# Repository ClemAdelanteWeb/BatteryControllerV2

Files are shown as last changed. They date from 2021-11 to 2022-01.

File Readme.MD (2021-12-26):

### 2021-12-26 
Refonte complète du PCB pour y intégrer une horloge et un support de carte SD pour faire du logging.

Ajout d'une sortie Charging qui permet de couper / lancer une source de charge en fonction de l'état de la batterie.

Une temporisation de quelques secondes a été insérée pour que cette sortie Charging = 0 avant que le relais de Charge ne soit réellement ouvert (charge bloquée), pour éviter quel l'alternateur ne débite d'un coup dans la batterie moteur ou que l'alternateur d'arbre continue de débiter à fond dans la batterie moteur.

Une sortie RS485 est intégrée pour afficher les informations depuis un autre Arduino. L'arduino NANO manque cruellement de RAM et SRAM pour permettre d'autre développement, comme le logging des valeurs les plus hautes ou plus basses (tensions de la batterie ou des cellules), etc.

Ces développements se feront peut-être avec un Arduino Nano Every ou STM32 Nucleo par exemple. Mais je réfléchis à une V3 avec un ESP32, ce qui permettrait d'émettre les informations en WIFI ou bluetooth BLE.

VIA RS485, les commandes sont les suivantes :
- 0 : print status
- 1 : print all data stored in SD CARD
- 9 : remove SD card file
- 8 : create SD Card file and add first entry in it

### dernier update 2020-01-08
Modification du comportement de la détection du voltage minimum de la batterie suite à un problème pendant 2 mois d'absence.
Le SOC était toujours à 100% parce que le Victron ne détectait pas les petites consommations de courant (Victron BMV lui-même, contrôleur de batterie, conso du régulateur de panneau solaire). Le relai de charge ne s'est dont pas fermé et à mon retour la batterie était à 10.7v

J'ai aussi rajouté des détections de voltage trop haut ou trop bas pour chaque cellule. Respectueusement 2.8v et 3.8v.

### Gestion des relais de charge et décharge dans un système de batterie Lifepo4.

Dans un système avec batteries au lifepo4, il faut pouvoir couper la charge quand les batteries sont pleines, pour ne pas passer en mode float et abimer les batteries sur le long terme.

Toute décharge doit être rendue impossible si les batteries ont atteint leur maximum de capacité de décharge (en général 80%), tout en laissant la charge se faire.
Il faut donc deux relais qui permettent de bloquer la charge, bloquer la décharge et bloquer les deux ce qui ferait l'équivalent d'un coupe circuit.

Il existe plusieurs sortent de relais. Les classiques à solenoide qui sont finalement constitués d'une lamelle à ressort que vient plaquer et fermer une bobine qui une fois alimentée crée un champ magnétique. Cette bobine c'est une solénoide, qu'on retrouve dans tous les relais classiques.

Il est aisé de déduire que ce type de relai consomme de l'énergie en permanence pour que le contact se fasse et le courant puisse passer. Pour les meilleurs d'entre eux 0.1A 24/24h ce qui fait un total de 2.4Ah par jour et comme il en faut 2 on arrive à une consommation de 4.8Ah par jour.

Un relai classique consomme entre 0.3 et 1A, on arrive dans ce cas à des consommations non négligeables de 14Ah à 48Ah par jour, simplement pour alimenter des relais qui servent à :
- Celui de charge (Charge) : couper les différentes charges et ne pas laisser la batterie Lifepo4 en mode float
- Celui de décharge (Load) : isoler de toute décharge profonde la batterie Lifepo4 tout en laissant la possibilité de la charger.

Les relais à solénoide optimisés (0.1A) sont très chers et même 5Ah par jour étaient de trop pour moi. 

Il existe aussi des relais mosfet qu'on trouve partout en électronique de puissance. S'il est plus compliquer d'estimer leur consommation lorsqu'ils sont passant, on comprend vite qu'elle est élevée puisqu'il faut un radiateur pour dissiper la chaleur qu'il produit.
Les mosfets sont aussi évincés de ma liste.

Heureusement il reste une solution : les relais bi-stable (ou latching relay en anglais).
Ceux-ci possèdent deux solénoides par relai. Un pour ouvrir le contact et un autre pour le fermer. Cette fois ci, et au contraire des relais classique, la position de la lamelle est permanente. C'est à dire qu'il n'y a pas besoin d'alimenter en permanence le solénoide pour créer un champ magnétique et forcer à lamelle à rester en place. Ici, comme pour un interrupteur à deux positions le relai ne consomme du courant que pour changer son état.

C'est parfait sauf que ça complique les choses puisqu'il y a deux bobines à alimenter par relai. Et comment savoir dans quelle position est le relai, ouvert ou fermé ?

J'ai choisi d'utiliser les relais Blue Sea ML-RBS qui ne consomment aucun courant et ont aussi une sortie qui permet de connaitre l'état du relai (ouvert ou fermé). On peut récupérer cette information et la traiter avec l'Arduino.

Il faut au moins 2A en 12v pour ouvrir ou fermer le relai. L'arduino seul n'est pas capable de fournir une tel intensité ni un telle tension. J'utilise donc une cascade de transisteurs.

Le soucis majeur lors de la création de la carte a été que les relais sont cablés en High Side, c'est à dire que les solenoides se trouvent du côté positif du circuit ce qui implique d'utiliser une cascade de transistor pour les activer avec un système PNP + NPN.

Pour déterminer le SOC (capacité restante dans la batterie en pourcentage) et l'utiliser pour gérer mes relais, j'utilise mon controleur de batterie Victron BMV702 qui fournit cette information par son port de communication (VE Direct). 

J'ai ensuite pris le parti d'acquérir les tensions des 4 cellules que composent la batteries pour controller les écarts entre les cellules, vérifier si l'une d'entre elles venait à être sous-chargée ou sur-chargée et connaitre la tension totale de la batterie.

Autant d'informations capitales qui permettent aussi de controller les relais sans les données fournies par le Victron, si celui-ci venait à tomber en panne.

J'ai aussi ajouté un bouton ON/OFF pour désactiver l'utilisation du SOC venant du Victron.

L'arduino reçoit donc les informations suivantes : 
- Etat du relai de charge
- Etat du relai de décharge
- SOC via le controleur Victron
- Tension de chaque cellule
- Utilisation du Victron ON / OFF

Par la suite, je vais créer un petit écran pour afficher toutes les données (voltage des cellules, état des relais, cycle de charge ou cycle de décharge, sur-tension ou sous-tension détectée). 

Pour des batteries au lithium, il n'est pas recommandé de maintenir la charge à 100% (mode float).
Aujourd'hui le programme ne possède qu'un cycle de charge qui va de 95 à 100% du SOC. Un cycle se compose comme ceci : la batterie se charge jusqu'à 100%, puis la charge est bloquée jusqu'à ce que la batterie se vide de 5%. A 95% de SOC, donc, la charge est de nouveau autorisée. 

Pour prolonger la durée de vie des batteries lithium, le SOC idéal est entre 50 et 70%. Ce serait intéressant de pouvoir faire des cycles entre 50 et 70% lorsque l'on est au port par exemple et qu'on n'a pas besoin de toute la capacité de la batterie puisqu'elle est rechargée au quai. 
Une autre utilisation de ce cycle 50-70% pourrait être faite en hivernage, période pendant laquelle la batterie n'est pas solicitée mais que la charge peut être faite par un panneau solaire par exemple. Grâce au controleur il serait possible de laisser tourner un petit ventilateur 12V dans les endroits qui en auraient besoin, par exemple, en aillant la certitude qu'il ne déchargera pas la batterie en dessous de 50%.

Une fois que l'autonomie totale est requise on retourne sur le cycle normal qui est de 95 à 100%.

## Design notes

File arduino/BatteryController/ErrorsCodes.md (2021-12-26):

#1 SOC min reached : now / min 
    values : SOC actual/ SOC Min param
#2 High Voltage detected
    values : Voltage
#3 High voltage detected, Force Opening Charge Relay 
#4  Voltage Max Reset reached, charge relay closing
#5 Low voltage detected
#6 Charge Relay Closing
    value : SOC, Battery voltage
#7 Low voltage detected, Load relay force closing
#8 Charge relay force closing. 2nd attempt
#9 Voltage min Reset reached. Load Relay closing
#10 No Voltage detected Load Relay Force Open
    value : temps écoulé depuis dernière valeur en ms
#11 Cells Voltage diff high, Load relay Force open
    value : mV cell diff 
#12 Reset OK Cells Voltage diff < Rst. Closing Load Relay
#13 Cells diff upd > 10s
#14 ADS 3 cell voltage not available
#15 SOC Current > SOC Min
    => normal routine detection
#16 Load relay closing, routine without SOC
#17 SOC Current < SOC Max Charge relay closing
    => can happen when forcing open Charge Relay manually 
#18 Charge relay closing, routine without SOC
#19 SOC min reset reached
    values : SOCCurrent/SOCMinReset
#20 Loading relay closing, routine without SOC    
#21 Cancelling Discharge Cycling
    values : SOCCurrent/SOCMaxReset
#22 Cancelling Discharge Cycling without SOC
#23 Wrong Charging relay state, opening 
    => Can append when manually closing Charge Relay
    => Can also append when HighVoltage detected is going to be RESET AND SOC is just reconnected, normal routine
#24 Wrong Loading relay state, opening
#25 SOC Current > Max : current/max
#26 High individual cell voltage
    value : num / mV
#27 RST OK : high V cell good
    value : Highest cell voltage in mV
#28 Low cell voltage
    value : num / mV
#29 RST Cell Voltage
    value : Lowest cell voltage in mV
#30 Low T°
    value : T°
#31 Low T°
    value : T°
#32 T° min reset, closing charging relay

               MessageTemp = (String)SOCCurrent + F(",") + TxtSpacer + (String)SOCMin;
               logDataMessNum(15);

sprintf(messageStatusBuffer, ("$%d;%d;%d;;%d;%d;%d;%d;%d;;%d;%d;;%d;%d;%d;%d;;%d;%d;%d;%d;%d;%d*"),
          getBatteryVoltage(),
          getBatteryTemperature(),
          getBatterySOC(),
          // vide
          getAdsCellVoltage(0),
          getAdsCellVoltage(1),
          getAdsCellVoltage(2),
          getAdsCellVoltage(3),
          getMaxCellVoltageDifference(),
          // vide
          ChargeRelay.getState(),
          LoadRelay.getState(),
          // vide
          SOCChargeCycling,
          SOCDischargeCycling,
          isEnabledBMVSerialInfos(),
          isUseBMVSerialInfos(),
          // vide
          LowVoltageDetected,
           ,
          CellsDifferenceDetected,
          CellVoltageMinDetected,
          CellVoltageMaxDetected,
          LowBatteryTemperatureDetected

  );

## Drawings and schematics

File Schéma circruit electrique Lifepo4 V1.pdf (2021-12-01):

@

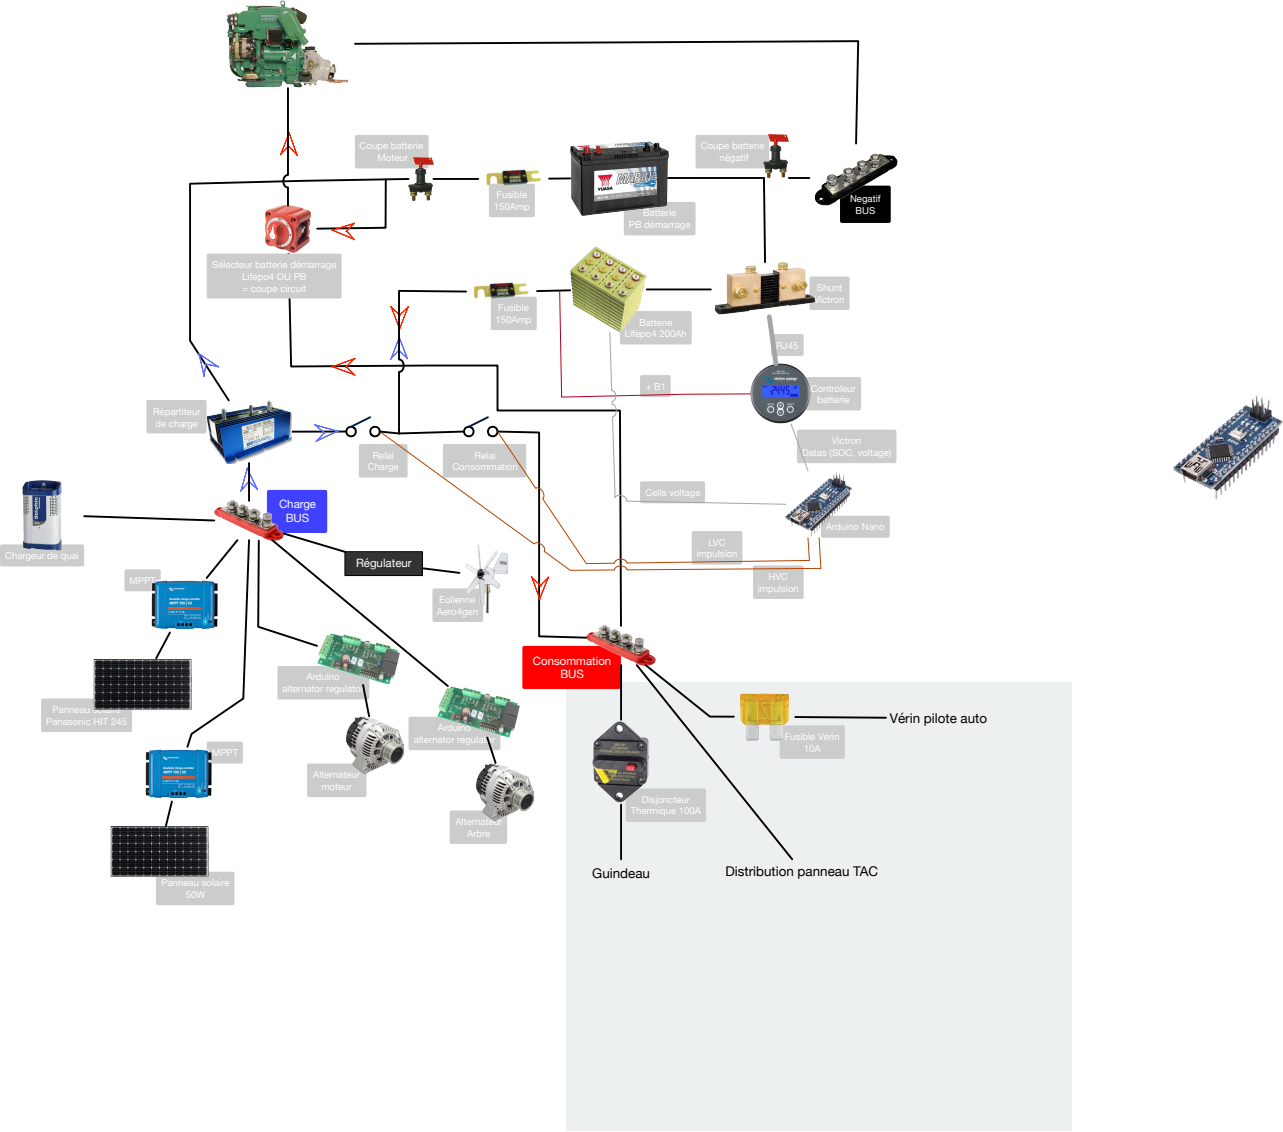
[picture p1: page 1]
Fusible Vérin 10A; Disjoncteur Thermique 100A; Coupe batterie négatif; Cells voltage; LVC impulsion; HVC impulsion; Arduino Nano; Controleur; batterie; Fusible 150Amp; Shunt Victron; Negatif BUS; Eolienne Aero4gen; Batterie PB démarrage; Batterie Lifepo4 200Ah; Arduino alternator regulator; Alternateur moteur; Alternateur Arbre; MPPT; Panneau solaire Panasonic HIT 245; Charge BUS; Consommation BUS; Répartiteur de charge; Relai Charge; Relai Consommation; Guindeau; Distribution panneau TAC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

Sélecteur batterie démarrage
Lifepo4 OU PB
= coupe circuit

Victron
Datas (SOC, voltage)

Chargeur de quai

Vérin pilote auto

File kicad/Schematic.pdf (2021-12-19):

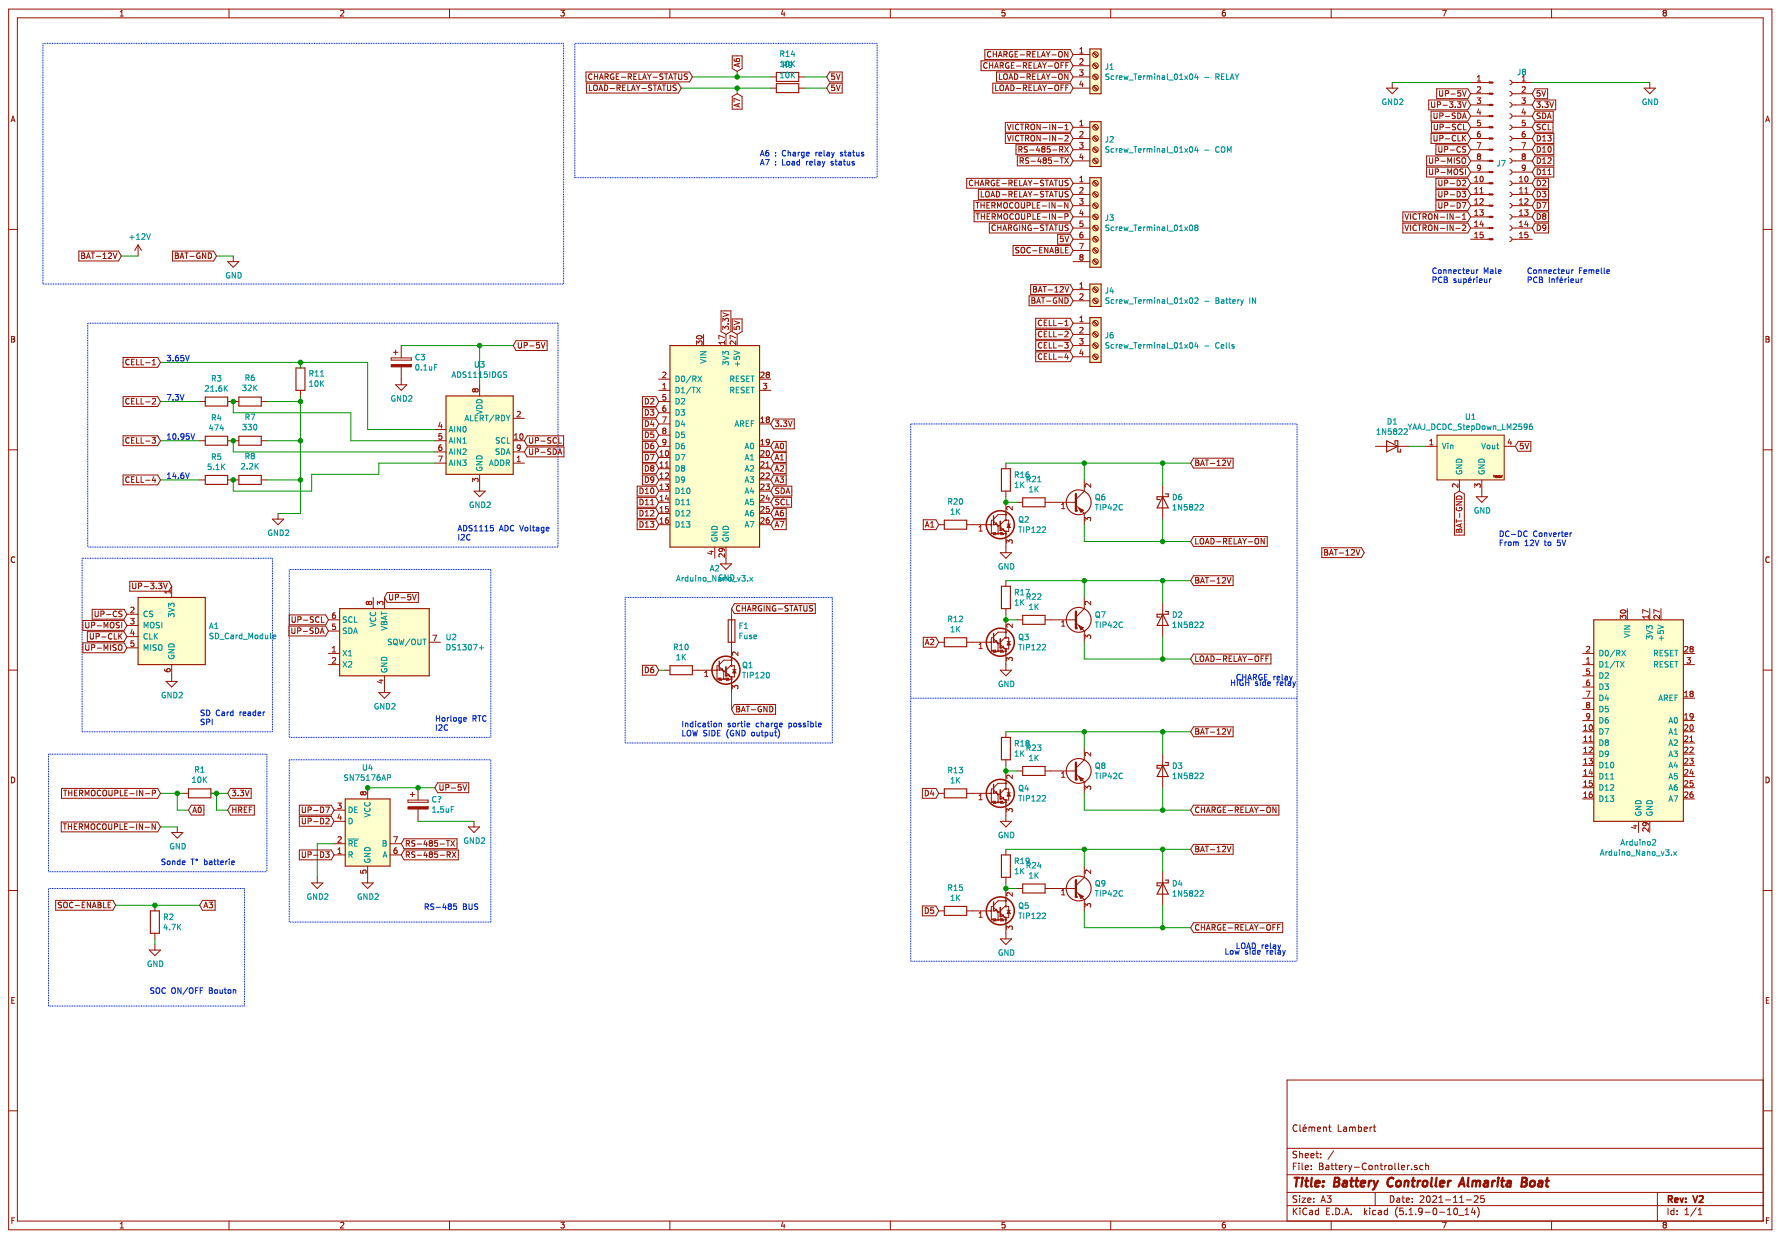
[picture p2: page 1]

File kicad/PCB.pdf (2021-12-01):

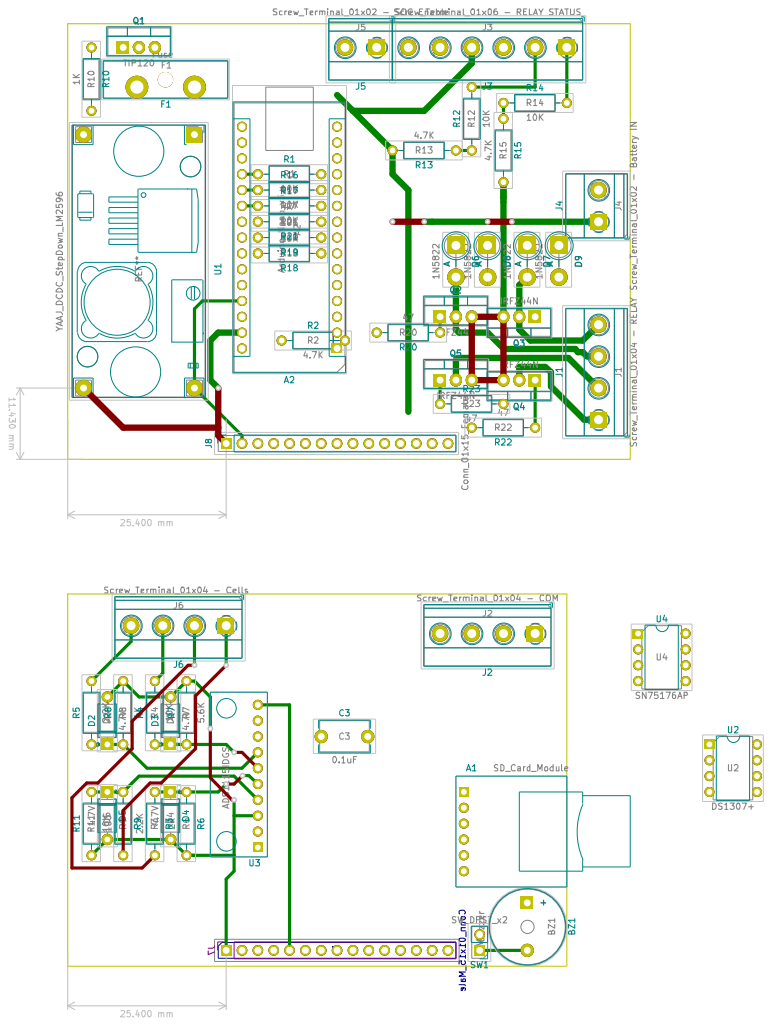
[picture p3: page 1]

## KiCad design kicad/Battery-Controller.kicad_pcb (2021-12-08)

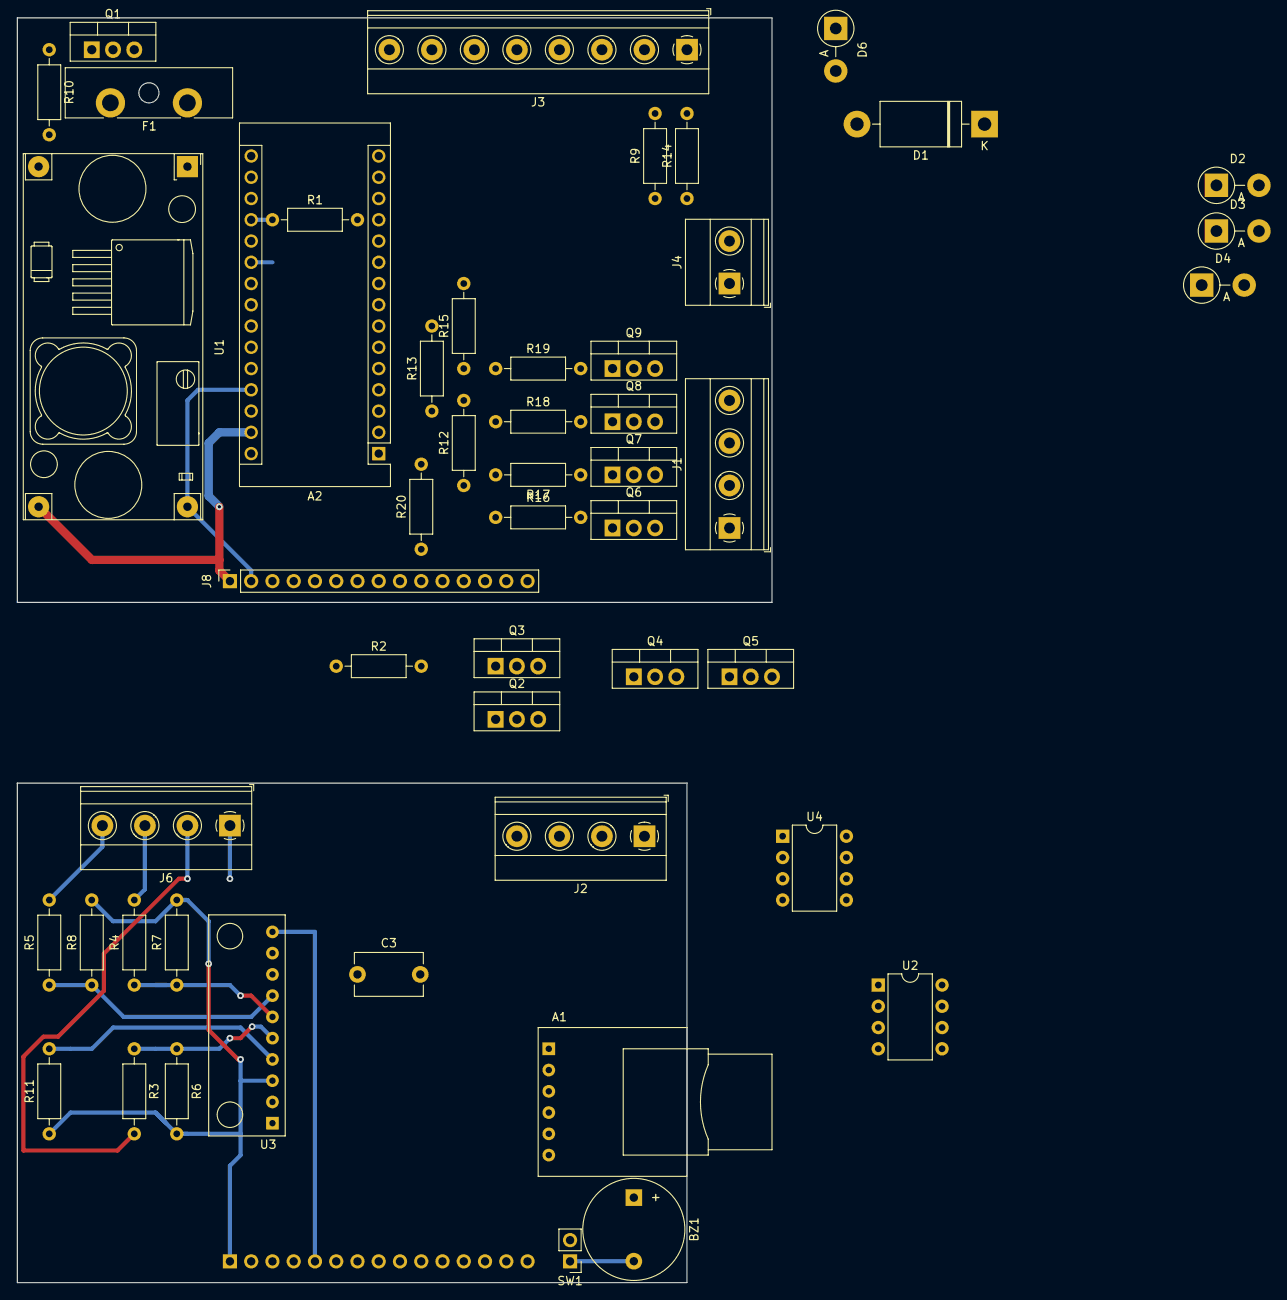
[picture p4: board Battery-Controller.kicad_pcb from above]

Board: 2 copper layers, 90.2 x 151.1 mm, 51 parts (1 on the bottom side), 64 nets.

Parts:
A1: SD_Card_Module
A2: Arduino_Nano_v3.x; Arduino_Nano
BZ1: Buzzer; Buzzer_12x9.5RM7.6
C3: 0.1uF; C_Disc_D8.0mm_W5.0mm_P7.50mm
D1: 1N5822; D_DO-201AD_P15.24mm_Horizontal
D2, D3, D4, D6: 1N5822; D_5W_P5.08mm_Vertical_AnodeUp
F1: Fuse; Fuseholder_Blade_ATO_Littelfuse_Pudenz_2_Pin
J1: Screw_Terminal_01x04 - RELAY; TerminalBlock_Phoenix_MKDS-1,5-4-5.08_1x04_P5.08mm_Horizont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
J2: Screw_Terminal_01x04 - COM; TerminalBlock_Phoenix_MKDS-1,5-4-5.08_1x04_P5.08mm_Horizont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
J3: Screw_Terminal_01x08; TerminalBlock_Phoenix_MKDS-1,5-8-5.08_1x08_P5.08mm_Horizont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
J4: Screw_Terminal_01x02 - Battery IN; TerminalBlock_Phoenix_MKDS-1,5-2-5.08_1x02_P5.08mm_Horizont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
J6: Screw_Terminal_01x04 - Cells; TerminalBlock_Phoenix_MKDS-1,5-4-5.08_1x04_P5.08mm_Horizont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
J7: Conn_01x15_Male; PinHeader_1x15_P2.54mm_Vertical
J8: Conn_01x15_Female; PinSocket_1x15_P2.54mm_Vertical
Q1: TIP120; TO-220-3_Vertical
Q2, Q3, Q4, Q5: TIP122; TO-220-3_Vertical
Q6, Q7, Q8, Q9: TIP42C; TO-220-3_Vertical
R1, R9, R11, R14: 10K; R_Axial_DIN0207_L6.3mm_D2.5mm_P10.16mm_Horizontal
R2: 4.7K; R_Axial_DIN0207_L6.3mm_D2.5mm_P10.16mm_Horizontal
R3: 21.6K; R_Axial_DIN0207_L6.3mm_D2.5mm_P10.16mm_Horizontal
R4: 474; R_Axial_DIN0207_L6.3mm_D2.5mm_P10.16mm_Horizontal
R5: 5.1K; R_Axial_DIN0207_L6.3mm_D2.5mm_P10.16mm_Horizontal
R6: 32K; R_Axial_DIN0207_L6.3mm_D2.5mm_P10.16mm_Horizontal
R7: 330; R_Axial_DIN0207_L6.3mm_D2.5mm_P10.16mm_Horizontal
R8: 2.2K; R_Axial_DIN0207_L6.3mm_D2.5mm_P10.16mm_Horizontal
R10, R12, R13, R15, R16, R17, R18, R19, R20: 1K; R_Axial_DIN0207_L6.3mm_D2.5mm_P10.16mm_Horizontal
SW1: SW_DPST_x2; PinHeader_1x02_P2.54mm_Vertical
U1: YAAJ_DCDC_StepDown_LM2596
U2: DS1307+; DIP-8_W7.62mm
U3: ADS1115IDGS; ADC1115_ADC_Module
U4: SN75176AP; DIP-8_W7.62mm

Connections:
3.3V: A2.17, J8.3, R1.2
5V: A2.27, J3.6, J8.2, R9.1, R14.1, U1.4
A0: A2.19, J3.4, R1.1
A1: A2.20, R20.2
A2: A2.21, R12.2
A3: A2.22, J3.7, R2.1
A6: A2.25, J3.1, R14.2
A7: A2.26, J3.2, R9.2
BAT-12V: D2.2, D3.2, D4.2, D6.2, F1.1, J4.1, Q6.2, Q7.2, Q8.2, Q9.2, R16.1, R17.1, R18.1, R19.1
BAT-GND: A2.29, J3.3, J4.2, J8.1, Q2.3, Q3.3, Q4.3, Q5.3, R2.2, U1.2, U1.3
CELL-1: J6.1, R11.2, U3.4
CELL-2: J6.2, R3.2
CELL-3: J6.3, R4.2
CELL-4: J6.4, R5.2
CHARGE-RELAY-OFF: D2.1, J1.2, Q7.3
CHARGE-RELAY-ON: D6.1, J1.1, Q6.3
CHARGING-STATUS: J3.5, Q1.3
D2: A2.5, J8.10
D3: A2.6, J8.11
D4: A2.7, R13.2
D5: A2.8, R15.2
D6: A2.9, R10.2
D7: A2.10, J8.12
D8: A2.11, J8.13
D9: A2.12, J8.14
D10: A2.13, J8.7
D11: A2.14, J8.9
D12: A2.15, J8.8
D13: A2.16, J8.6
LOAD-RELAY-OFF: D4.1, J1.4, Q9.3
LOAD-RELAY-ON: D3.1, J1.3, Q8.3
unnamed: BZ1.2, SW1.1
unnamed: D1.1, U1.1
unnamed: F1.2, Q1.2
unnamed: Q1.1, R10.1
unnamed: Q2.1, R20.1
unnamed: Q2.2, Q6.1, R16.2
unnamed: Q3.1, R12.1
unnamed: Q3.2, Q7.1, R17.2
unnamed: Q4.1, R13.1
unnamed: Q4.2, Q8.1, R18.2
unnamed: Q5.1, R15.1
unnamed: Q5.2, Q9.1, R19.2
unnamed: R3.1, R6.1, U3.5
unnamed: R4.1, R7.1, U3.6
unnamed: R5.1, R8.1, U3.7
RS-485-OUT1: J2.3, U4.7
RS-485-OUT2: J2.4, U4.6
SCL: A2.24, J8.5
SDA: A2.23, J8.4
TUP-01: A1.6, BZ1.1, C3.2, J7.1, R6.2, R7.2, R8.2, R11.1, U2.4, U3.3, U4.5
UP-3.3V: A1.1, J7.3
UP-5V: C3.1, J7.2, U2.3, U3.8, U4.8
UP-CLK: A1.4, J7.6
UP-CS: A1.2, J7.7
UP-D2: J7.10, U4.4
UP-D3: J7.11, U4.1
UP-D7: J7.12, SW1.2
UP-MISO: A1.5, J7.8
UP-MOSI: A1.3, J7.9
UP-SCL: J7.5, U2.6, U3.10
UP-SDA: J7.4, U2.5, U3.9
VICTRON-IN-1: J2.1, J7.13
VICTRON-IN-2: J2.2, J7.14

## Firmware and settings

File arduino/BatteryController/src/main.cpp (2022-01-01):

#include <Arduino.h>
#include <SPI.h>
#include "AltSoftSerial.h"

#include "SoftwareSerial.h"
#include "Thread.h"
#include "BlueSeaLatchingRelay.h"
#include "ADS1X15.h"

// Utilisation du module RTC qui permet de logger avec l'heure réelle
#define IS_RTC 1

#define IS_SDCARD 1

// Utilisation de serial
#define IS_SERIAL 0

#define IS_RS485 1

// Définit la date dans le module RTC
#define SET_DATE 0

// print memory free
#define IS_PRINT_MEMORY 1

//------
// SETTINGS

// Opening charge relay for SOC >= SOCMax
const int SOCMax = 1000;

// Re-Close Charge Relay when SOCMaxReset is reached
const int SOCMaxReset = 950;

// Opening Load relay if SOC <= SOCmin
const int SOCMin = 180;

// Re-Close Load Relay when SOCMinReset is reached
const int SOCMinReset = 200;

// SOC Maximum time considerated valid
// must be > 10 000ms
// in mS
const int SOCMaxTimeValid = 30000;

// Maximum Voltage security
// default 13800
const int BatteryVoltageMax = 13800; // 13,8v = 3,45v / Cell

// Waiting for Max Reset Voltage after reaching Max Voltage (time to discharge the battery enough to use it)
// default 13360
const int BatteryVoltageMaxReset = 13200;

// Minimum Voltage security
// default 12000
const int BatteryVoltageMin = 12000; // 12V = 3v / Cell

// Waiting for Min Reset Voltage after reaching Min Voltage (time to re-charge the battery enough to use it)
// default 12800
const int BatteryVoltageMinReset = 12800; // 12,9  = 3,225v / Cell

// Minimum operating cell voltage
// default 2800
const int CellVoltageMin = 2800;

// Minimum cell voltage after a min detected
const int CellVoltageMinReset = 2900;

// Maximum operating cell voltage
// default 3600
const int CellVoltageMax = 3600;

// Maximum cell voltage after max dected
const int CellVoltageMaxReset = 3350;

// Delay time before opening the Charge Relay
// The charge Output status will be HIGH right away and the charge relay will be opened after the delay
// default 5 sec (5000)
const unsigned int delayBeforeChargeOpening = 5000;

//------
// PINS PARAMS
const byte LoadRelayClosePin = A1; // A1
const byte LoadRelayOpenPin = A2;  //A2
const byte LoadRelayStatePin = A7; //A7

const byte ChargeRelayClosePin = 4;  //4
const byte ChargeRelayOpenPin = 5;   //5
const byte ChargeRelayStatePin = A6; //A6

// if pin HIGH, BMV infos are collected
const byte ActivateBmvSerialPin = A3;

const byte ThermistorSensorPin = A0;

const byte RS485PinRx = 3;
const byte RS485PinTx = 2;
const byte RS485PinDE = 7;

const byte ChargingStatusOutputPin = 6;

// END PINS PARAMS
//------

// Number of cells in the battery
const byte cellsNumber = 4;

// ADS1115 Calibration at 10v *1000
// Ex: 10 / 18107 = 0,000552273
// cell 1, 2, 3, 4 etc
const float adc_calibration[cellsNumber] = {
    0.11947112,
    0.22990510,
    0.32871799,
    0.422045};

// number of sample taken to average cell voltage
// mode=4 so 128 samples per seconde = 8ms/sample
// delay of 2ms between samples so
#define ADS_SAMPLE_NBR 10

// LOGGING Params
#if IS_RTC
#include <TimeLib.h>
#include <DS1307RTC.h>
// RTC date time module
tmElements_t tm;
#endif

#if SET_DATE
const char *monthName[12] = {
    "Jan", "Feb", "Mar", "Apr", "May", "Jun",
    "Jul", "Aug", "Sep", "Oct", "Nov", "Dec"};
#endif

#if IS_PRINT_MEMORY
#include <MemoryFree.h>
#endif
// Log on SD Card

#if IS_SDCARD
#include <SdFat.h>
SdFat sd;
SdFile logFile;

uint8_t SDCardPinSelect = 10;
#define DataLogFile "log.txt"
#endif

//------
// Temperature sensor settings

const int ThermistorNominal = 11700;          // // resistance at 25 degrees C
const byte ThermistorTemperatureNominal = 20; // temp. for nominal resistance (almost always 25 C)
const byte ThermistorNbrSamples = 5;          // how many samples to take and average, more takes longer
const int ThermistorBetaCoefficient = 4370;   // The beta coefficient of the thermistor (usually 3000-4000)
const int ThermistorSerieResistor = 10000;    // the value of the 'other' resistor

// Température minimum pour autorisation de charge
// => ne pas charger une batterie au lithium en dessous de 0°
// la sonde n'étant pas parfaitement calibrée, 1° réel = 4° sur la sonde
const byte TemperatureMinCharge = 4;
const byte TemperatureMinChargeReset = 5; // valeur à partir de laquelle on autorise à nouveau la charge de la batterie

// END SETTINGS
//-------

// TEXTES

// Program declarations

// RX pin 8 Tx pin 9 for Serial Victron BMV communication
AltSoftSerial Bmv;

#if IS_RS485
// RS485 communication
SoftwareSerial RS485(RS485PinRx, RS485PinTx);
#endif

Thread RunApplication = Thread();

// ADS1115 on I2C0x48 adress
ADS1115 ADS(0x48);

// Relays declaration
BlueSeaLatchingRelay LoadRelay;
BlueSeaLatchingRelay ChargeRelay;

uint16_t BatteryCellsVoltage[cellsNumber];

uint16_t BatteryVoltage;

uint16_t LowestCellVoltage;
uint16_t HighestCellVoltage;

unsigned long BatteryVoltageUpdatedTime;

int CellsDifferenceMax;

unsigned int SOC;
unsigned int SOCTemp;
unsigned int SOCCurrent;
unsigned long SOCUpdatedTime;

// If SOCDischargeCycling = true : the battery is full and Charge Relay is open
bool SOCDischargeCycling = false;

// if SOCChargeCycling = true : the battery is empty and Load relay is opened
bool SOCChargeCycling = false;

// If High voltage has been detected (waiting for HighVoltageReset)
// Charge relay is closed
bool HighVoltageDetected = false;

// If Low voltage has been detected (waiting for LowVoltageReset)
// Load relay is closed
bool LowVoltageDetected = false;

// If an individual cell voltage is too low
// waiting for a higher value
// force charging, alarm is ON
bool CellVoltageMinDetected = false;

// If an individual cell voltage is too high
// waiting for a lower value
// force discharging, alarm is ON
bool CellVoltageMaxDetected = false;

// If a low temperature is detected
// waiting for a higher value
// charging forbidden
bool LowBatteryTemperatureDetected = false;

// victron checksum
byte checksumBmv = 0;
String V_buffer;
char cBmv;

// Serial communication
const byte numChars = 2;
char receivedChars[numChars]; // an array to store the received data
boolean newData = false;

// Temperature
int BatteryTemperature;

String MessageTemp;

byte isfirstrun = 1;

#define ValuesSpacer F("/")
//static const char ValuesSpacer[] = F("/");
int i;

void logData(String message, byte nivel = 0);
void logDataMessNum(int num, String values = "", byte nivel = 0);

String getDateTime();

void printParams();

#if IS_PRINT_MEMORY
void printMemory();
#endif

void printStatus();

// int getMaxCellVoltageDifference();
uint16_t getAdsBatteryVoltage();
void run();

#if SET_DATE
bool getTime(const char *str);
bool getDate(const char *str);
#endif

void setup()
{
  pinMode(LoadRelayClosePin, OUTPUT);
  pinMode(LoadRelayOpenPin, OUTPUT);
  pinMode(ChargeRelayClosePin, OUTPUT);
  pinMode(ChargeRelayOpenPin, OUTPUT);
  pinMode(ChargeRelayStatePin, INPUT_PULLUP);
  pinMode(LoadRelayStatePin, INPUT_PULLUP);

  pinMode(ActivateBmvSerialPin, INPUT);

  // Pour la lecture de la température
  analogReference(EXTERNAL);

// Load Relay declaration
#if IS_SERIAL
  LoadRelay.name = "LR";
#endif

  LoadRelay.openPin = LoadRelayOpenPin;
  LoadRelay.closePin = LoadRelayClosePin;
  LoadRelay.statePin = LoadRelayStatePin;

// Charge Relay declaration
#if IS_SERIAL
  ChargeRelay.name = "ChR";
#endif
  ChargeRelay.openPin = ChargeRelayOpenPin;
  ChargeRelay.closePin = ChargeRelayClosePin;
  ChargeRelay.statePin = ChargeRelayStatePin;
  ChargeRelay.delayBeforeOpening = delayBeforeChargeOpening;

// Serial.begin(19200); // fonctionnait sur la v2 à cette vitesse
#if IS_SERIAL
  Serial.begin(38400);
#endif

  Bmv.begin(19200); // Victron Baudrate = 19200

#if IS_RS485
  RS485.begin(57600);
  pinMode(RS485PinDE, OUTPUT);
  digitalWrite(RS485PinDE, LOW); // receiving mode
#endif

  RunApplication.onRun(run);
  RunApplication.setInterval(1500); // 1.5 sec loop

  ADS.begin();
  ADS.setGain(1);     // 4V volt max for each entry
  ADS.setMode(1);     // mesures à la demande
  ADS.setDataRate(4); // vitesse de mesure 4 = 128 sample / Seconde
  ADS.readADC(0);     // Et on fait une lecture à vide, pour envoyer tous ces paramètres

#if IS_SDCARD
  // Initialisation Carte SD
  if (!sd.begin(SDCardPinSelect))
  {
    // sd.initErrorHalt();
  }
#endif

#if SET_DATE
  bool parse = false;
  bool config = false;
  // get the date and time the compiler was run
  if (getDate(__DATE__) && getTime(__TIME__))
  {
    parse = true;
    // and configure the RTC with this info
    if (RTC.write(tm))
    {
      config = true;
    }
  }

#endif

#if IS_SERIAL
  Serial.println(F("STP END"));
#endif

  // Serial.println(F("END STP"));
}

// Enregistrement de toutes les tensions des cellules
void checkCellsVoltage()
{
  unsigned long averageCell;
  byte iTemp2;
  int iCell; // ne pas toucher le type
  uint16_t vTemp;
  uint16_t tempCellV = 0;
  for (iCell = (cellsNumber - 1); iCell >= 0; iCell--)
  {
    averageCell = 0;

    // take N samples in a row, with a slight delay
    for (iTemp2 = 0; iTemp2 < ADS_SAMPLE_NBR; iTemp2++)
    {
      averageCell += ADS.readADC(iCell);
      // Serial.println(averageCell);
      delay(9);
    }

    // moyenne des échantillons
    averageCell = averageCell / ADS_SAMPLE_NBR;

    vTemp = (int)(averageCell * adc_calibration[iCell]);

    if (vTemp < 0)
    {
      vTemp = 0;
    }
    BatteryCellsVoltage[iCell] = vTemp;
  }

  // Getting highest Cell and lowest Cell voltage
  LowestCellVoltage = 0;
  HighestCellVoltage = 0;
  uint16_t tempCellVA = 0;
  uint16_t tempCellVB = 0;
  for (iCell = (cellsNumber - 1); iCell >= 0; iCell--)
  {

    tempCellVA = BatteryCellsVoltage[iCell];

    if (iCell > 0)
    {
      tempCellVB = BatteryCellsVoltage[iCell - 1];
      tempCellV = tempCellVA - tempCellVB;
    }
    else
    {
      tempCellV = tempCellVA;
    }

    // setting the highest cell value
    if (tempCellV > HighestCellVoltage)
    {
      HighestCellVoltage = tempCellV;
    }

    // setting the lowest cell value
    if ((tempCellV < LowestCellVoltage) || (LowestCellVoltage == 0))
    {
      LowestCellVoltage = tempCellV;
    }
  }
}

/**
  Return cell Voltage
*/
uint16_t getAdsCellVoltage(int cellNumber)
{

  //  for (int element : BatteryCellsVoltage) // for each element in the array
  //    Serial.println(element);

  return BatteryCellsVoltage[cellNumber];
}

/**
   Get Battery voltage
   try with ADS1115 First, Victron BMV next
*/
uint16_t getBatteryVoltage()
{
  uint16_t BatteryVoltageTemp = getAdsBatteryVoltage();

  if (BatteryVoltageTemp)
  {
    return BatteryVoltageTemp;
  }

  return 0;
}

/**
   Return Battery Voltage (12v) for current loop
*/
uint16_t getAdsBatteryVoltage()
{
  uint16_t BatteryVoltageTemp2 = getAdsCellVoltage((cellsNumber - 1));

  if (BatteryVoltageTemp2 > 100)
  {
    BatteryVoltageUpdatedTime = millis();
  }
  else
  {
    // ADS 3 cell voltage not available
    logDataMessNum(14, "", 1);
  }

  return BatteryVoltageTemp2;
}

/**
   Return SOC value
*/
int getBatterySOC()
{
  if ((millis() - SOCUpdatedTime) < SOCMaxTimeValid)
  {
    return SOC;
  }
  else
  {
    return 0;
  }
}

// Reading Victron Datas
// And extracting SOC and Voltage values
void readBmvData()
{

  if (Bmv.available())
  {
    cBmv = Bmv.read();
    checksumBmv += cBmv;

    if (V_buffer.length() < 80)
    {
      V_buffer += cBmv;
    }

    // end of line
    if (cBmv == '\n')
    {
      // Serial.println(V_buffer);
      if (V_buffer.startsWith(F("SOC")))
      {
        String temp_string = V_buffer.substring(V_buffer.indexOf("\t") + 1);
        SOCTemp = temp_string.toInt();
      }

      // end of serie
      if (V_buffer.startsWith(F("Checksum")))
      {

        byte result = checksumBmv % 256;

        // checksum OK
        if (result == 0)
        {
          SOC = SOCTemp;
          SOCUpdatedTime = millis();

#if IS_SERIAL
          Serial.println(F("SOC-UPD"));
#endif
        }

        // begin new serie
        checksumBmv = 0;
      }

      // begin new line
      V_buffer = "";
    }
  }
}

// Check if SOC Value is valid
boolean isSOCValid()
{
  if ((millis() - SOCUpdatedTime) < SOCMaxTimeValid)
  {
    return true;
  }

#if IS_SERIAL
  Serial.println(F("SOC NO VALID"));
#endif
  return false;
}

#if IS_SDCARD
void readSDCard()
{
  int data;

#if IS_RS485
  digitalWrite(RS485PinDE, HIGH);
#endif

#ifdef O_RDONLY
#else
#define O_RDONLY 0X00
#endif
  if (!logFile.open(DataLogFile, O_RDONLY))
  {

#if IS_RS485
    RS485.println(F("$E;NOSDFILE*"));
#endif

#if IS_SERIAL
    Serial.println(F("NOSDFILE"));
#endif
  }

#if IS_RS485
  // RS485.println(F("SDCARD"));
#endif

#if IS_SERIAL
// Serial.println(F("SDCARD"));
#endif

  while ((data = logFile.read()) >= 0)
  {
#if IS_SERIAL
    Serial.write(data);
#endif

#if IS_RS485
    RS485.write(data);
#endif

    delay(2);
  }

#if IS_RS485
  digitalWrite(RS485PinDE, LOW);
#endif

  // close the file:
  logFile.close();
}

void deleteFile()
{
  sd.remove(DataLogFile);
}
#endif
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
void loop()
{

  if (isfirstrun)
  {

    isfirstrun = 0;

    // première lecture des tensions
    checkCellsVoltage();

    // pour éviter d'avoir un SOC à 0 au lancement du programe
    SOC = 500;
    SOCUpdatedTime = millis();
    logData(F("Start"), 0);
  }

  // Collecte des infos Victron BMV702 si bouton ON
  if (isEnabledBMVSerialInfos())
  {
    readBmvData();
  }

#if IS_RS485
  // listening RS485 line
  handleRs485();
#endif

#if IS_SERIAL
  handleSerial();
#endif

  if (RunApplication.shouldRun())
  {
    RunApplication.run();
  }
}

/**
   Checking Voltage AND SOC and close or open relays
*/
void run()
{

  // Ne pas retirer, remet les états à appliquer à 0
  ChargeRelay.startCycle();
  LoadRelay.startCycle();

  // Va rechercher les valeurs des cellules pour cette boucle
  checkCellsVoltage();

#if IS_RS485
#if IS_PRINT_MEMORY
  printMemory();
#endif
  printStatus();
#endif

  // storing BatteryVoltage in temp variable
  int CurrentBatteryVoltage = getBatteryVoltage();

  // Get Actual battery  temperature
  BatteryTemperature = getBatteryTemperature();

  // Get actual SOC
  SOCCurrent = getBatterySOC();

  // --- Normal LOAD routines
  // checking if Load relay should be closed

  // first general condition
  // Normal operating range voltage and relay open
  if ((CurrentBatteryVoltage > BatteryVoltageMin) && (LoadRelay.getState() != LoadRelay.RELAY_CLOSE))
  {

    // not in special event
    if ((SOCChargeCycling == false) && (LowVoltageDetected == false))
    {

      // if using BMV SOC
      if (isUseBMVSerialInfos())
      {
        SOCCurrent = getBatterySOC();

        if ((SOCCurrent > SOCMin))
        {
          LoadRelay.setReadyToClose();

          // #15 SOC Current > SOC Min
          logDataMessNum(15);
        }
      }
      // Without SOC
      else
      {

        LoadRelay.setReadyToClose();

        // #16 Load relay closing, routine without SOC
        logDataMessNum(16);
      }
    }
  }

  // ---- Normal CHARGE routines
  // checking if Charge relay must be closed

  // first general condition
  if ((CurrentBatteryVoltage < BatteryVoltageMax) && (ChargeRelay.getState() != ChargeRelay.RELAY_CLOSE))
  {

    // not in special event
    if ((SOCDischargeCycling == false) && (HighVoltageDetected == false) && (LowBatteryTemperatureDetected == false))
    {

      // if using BMV SOC
      if (isUseBMVSerialInfos())
      {
        SOCCurrent = getBatterySOC();

        if ((SOCCurrent < SOCMax))
        {
          ChargeRelay.setReadyToClose();

          // #17 SOC Current < SOC Max Charge relay closing
          logDataMessNum(17);
        }
      }
      // Without SOC
      else
      {
        ChargeRelay.setReadyToClose();

        // #18 Charge relay closing, routine without SOC
        logDataMessNum(18);
      }
    }
  }

  //---
  // Cancelling Charge Cycling
  //
  if (SOCChargeCycling == true)
  {

    if (isUseBMVSerialInfos())
    {

      // if SOC > SOCMinReset
      if (SOCCurrent >= SOCMinReset)
      {

        SOCChargeCycling = false;
        LoadRelay.setReadyToClose();

        // #19 SOC min reset reached
        MessageTemp = (String)SOCCurrent + ValuesSpacer + (String)SOCMinReset;
        logDataMessNum(19, MessageTemp);
      }
    }
    else
    {
      // Case IF Charge Cycling = true while it shouldn't
      // could append after disconnecting SOC check and SOCChargeCycling was ON.
      // if Voltage battery high enough, we close the Load Relay

      if (LowVoltageDetected == false)
      {

        SOCChargeCycling = false;
        LoadRelay.setReadyToClose();

        // #20 Loading relay closing, routine without SOC
        logDataMessNum(20);
      }
    }
  }

  //---
  // Cancelling DisCharge Cycling
  //
  if (SOCDischargeCycling == true)
  {
    if (isUseBMVSerialInfos())
    {
      // if SOC < SOCMaxReset
      if (SOCCurrent <= SOCMaxReset)
      {
        SOCDischargeCycling = false;
        ChargeRelay.setReadyToClose();

        // #21 Cancelling Discharge Cycling
        MessageTemp = (String)SOCCurrent + ValuesSpacer + (String)SOCMaxReset;
        logDataMessNum(21, MessageTemp);
      }
    }
    else
    {
      // Case IF SOCDischargeCycling = true while it shouldn't
      // could append after disconnecting SOC check and SOCDischargeCycling was ON.
      // if Voltage battery Low enough, we close the Charge Relay
      if (HighVoltageDetected == false)
      {
        SOCDischargeCycling = false;
        ChargeRelay.setReadyToClose();

        // #22 Cancelling Discharge Cycling without SOC
        logDataMessNum(22);
      }
    }
  }

  // END NORMAL ROUTINES
  // -------------------------

  // if Charge relay has been manualy closed and doesn't match with the code
  // Relay must be opened
  // if not currently opening
  if (ChargeRelay.waitingForOpening != true)
  {
    if ((SOCDischargeCycling == true) || (HighVoltageDetected == true))
    {
      if ((ChargeRelay.getState() != ChargeRelay.RELAY_OPEN))
      {
        ChargeRelay.setReadyToOpen();

        // #23 Wrong Charging Relay state, opening
        MessageTemp = (String)ChargeRelay.getState() + F("!=") + (String)ChargeRelay.RELAY_OPEN;
        logDataMessNum(23, MessageTemp);
      }
    }
  }

  // if Load relay has been manualy closed
  // Relay must be opened
  if ((SOCChargeCycling == true) || (LowVoltageDetected == true))
  {
    if (LoadRelay.getState() != LoadRelay.RELAY_OPEN)
    {
      LoadRelay.setReadyToOpen();

      // #23 Wrong Loading Relay state, opening
      logDataMessNum(24);
    }
  }

  // STARTING EXCEPTIONAL EVENTS
  if (isUseBMVSerialInfos())
  {

    // SOC Max detection
    if ((SOCCurrent >= SOCMax) && (SOCDischargeCycling == false))
    {
      // if not currently opening
      if (ChargeRelay.waitingForOpening != true)
      {
        // Open Charge Relay
        SOCDischargeCycling = true;
        ChargeRelay.setReadyToOpen();

        // #25 SOC Current > Max : current/max"
        MessageTemp = (String)SOCCurrent + ValuesSpacer + (String)SOCMax;
        logDataMessNum(25, MessageTemp);
      }
    }
    // SOC Min detection when no Charging Cycle
    // => init Charging Cycling
    if ((SOCCurrent <= SOCMin) && (SOCChargeCycling == false))
    {

      // Open Load Relay
      SOCChargeCycling = true;

      LoadRelay.setReadyToOpen();
      MessageTemp = (String)SOCCurrent + ValuesSpacer + (String)SOCMin;
      logDataMessNum(1, MessageTemp, 0);
    }
  }

  //---
  // Voltage verifications
  if ((millis() - BatteryVoltageUpdatedTime) < 6000)
  {

    // if not currently opening
    if (ChargeRelay.waitingForOpening != true)
    {

      // NEW high voltage detection
      if ((CurrentBatteryVoltage >= BatteryVoltageMax) && (HighVoltageDetected == false))
      {
        // Open Charge Relay
        HighVoltageDetected = true;

        // set ready to open instead of forceOpen to let delay opening starts
        ChargeRelay.setReadyToOpen();

        MessageTemp = (String)(CurrentBatteryVoltage);
        logDataMessNum(2, MessageTemp, 0);
      }
      // HIGH VOLTAGE already detected
      else if (HighVoltageDetected == true)
      {

        // if not currently opening
        if (ChargeRelay.waitingForOpening != true)
        {
          // anormal state, force to open
          if (ChargeRelay.getState() == ChargeRelay.RELAY_CLOSE)
          {
            ChargeRelay.forceToOpen();
            logDataMessNum(3);
          }
        }

        // if Voltage battery low enough, we close the Charge Relay
        if (CurrentBatteryVoltage <= BatteryVoltageMaxReset)
        {
          HighVoltageDetected = false;
          ChargeRelay.setReadyToClose();

          logDataMessNum(4);
        }
      }
    }

    // Low voltage detection
    if ((CurrentBatteryVoltage <= BatteryVoltageMin) && (LowVoltageDetected == false))
    {
      // Open LoadRelay
      LowVoltageDetected = true;

      LoadRelay.forceToOpen();
      logDataMessNum(5);

      // Constrain battery to charge
      // in case of SOC >= max SOC, charge relay is open (can happen when very low consumption is not detected by Victron monitor)
      if (ChargeRelay.getState() == ChargeRelay.RELAY_OPEN)
      {

        ChargeRelay.forceToClose();

        MessageTemp = (String)getBatterySOC();
        MessageTemp += ValuesSpacer;
        MessageTemp += (String)CurrentBatteryVoltage;
        logDataMessNum(6, MessageTemp, 0);
      }
    }
    else
    {

      if (LowVoltageDetected == true)
      {

        if (LoadRelay.getState() == LoadRelay.RELAY_CLOSE)
        {

          LoadRelay.forceToOpen();
          logDataMessNum(7);
        }

        // Constrain battery to charge
        if (ChargeRelay.getState() == ChargeRelay.RELAY_OPEN)
        {
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

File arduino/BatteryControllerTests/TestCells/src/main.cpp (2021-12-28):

#include <Arduino.h>
#include <Wire.h>
#include <ADS1X15.h>

// ADS1115 on I2C0x48 adress
ADS1115 ADS(0x48);

#define NUMSAMPLES 20

// Number of cells in the battery
const int cellsNumber = 4;

// ADS1115 Calibration at 10v *1000
// Ex: 10 / 18107 = 0,000552273
// cell 1, 2, 3, 4 etc
const float adc_calibration[cellsNumber] = {
  0.11947112,
  0.22990510,
  0.32871799,
  0.422045
};


uint16_t BatteryCellsVoltage[cellsNumber];

uint16_t BatteryVoltage;
unsigned long BatteryVoltageUpdatedTime;

int CellsDifferenceMax;

void checkCellsVoltage();
void printStatus();
int getMaxCellVoltageDifference();
uint16_t getAdsCellVoltage(int cellNumber);


void setup(void) 
{
  Serial.begin(38400);
  Serial.println("Hello!");
  
  ADS.begin();
  ADS.setGain(1);       //4V volt
  ADS.setMode(1);       // mesures à la demande
  ADS.setDataRate(4);   // vitesse de mesure de 1 à 7
  ADS.readADC(0);       // Et on fait une lecture à vide, pour envoyer tous ces paramètres
}

void loop(void) 
{
  Serial.println("Loop");
  checkCellsVoltage();
  //printStatus();
  delay(5000);
}


void printStatus() {


  

  int iCell;
  for (iCell = 0; iCell <= cellsNumber; iCell++) {

      Serial.print("Cell "); Serial.print(iCell); Serial.print(" "); 
      Serial.println(getAdsCellVoltage(iCell));
  }

      Serial.print("Cell max diff : "); Serial.println(getMaxCellVoltageDifference());


}



void checkCellsVoltage()
{
  unsigned long averageCell;
  int iCell, iTemp2;
  uint16_t vTemp;
  uint16_t PastCell;

PastCell = 0;
  for (iCell = 0; iCell < cellsNumber; iCell++)
  {
    averageCell = 0;

    // take N samples in a row, with a slight delay
    for (iTemp2 = 0; iTemp2 < NUMSAMPLES; iTemp2++)
    {
      averageCell += ADS.readADC(iCell);
      // Serial.println(averageCell);
      delay(10);
    }

    // moyenne des échantillons
    averageCell = averageCell / NUMSAMPLES;

  

    vTemp = (int)(averageCell * adc_calibration[iCell]);

          Serial.print("Average : "); Serial.print(iCell+1); Serial.print(" ");
       Serial.print(averageCell); Serial.print(" / ");
       Serial.print(vTemp);Serial.print(" / ");
Serial.println((vTemp-PastCell));
    if (vTemp < 0)
    {
      vTemp = 0;
    }
PastCell = vTemp;

    BatteryCellsVoltage[iCell] = vTemp;
  }
  
}


/**
   Calculate max cell difference between all cells
   Return value in mV
*/
int getMaxCellVoltageDifference()
{

  // Cells voltages
  // unsigned int cellsVoltage[(cellsNumber - 1)];
  unsigned int minValue = 0;
  unsigned int maxValue = 0;
  unsigned int tempCellV = 0;
  int iTemp4;

  for (iTemp4 = (cellsNumber - 1); iTemp4 >= 0; iTemp4--)
  {
    if (iTemp4 > 0)
    {
      tempCellV = getAdsCellVoltage(iTemp4) - getAdsCellVoltage((iTemp4 - 1));
    }
    else
    {
      tempCellV = getAdsCellVoltage(iTemp4);
    }

    //    // enregistrement de la plus grande valeur
    if (tempCellV > maxValue)
    {
      maxValue = tempCellV;
    }

    if ((tempCellV < minValue) || (minValue == 0))
    {
      minValue = tempCellV;
    }
  }

  return maxValue - minValue;
}


/**
  Return cell Voltage
*/
uint16_t getAdsCellVoltage(int cellNumber) {

  //  for (int element : BatteryCellsVoltage) // for each element in the array
  //    Serial.println(element);

  return BatteryCellsVoltage[cellNumber];

}

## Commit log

2021-11-25 Fin schematic
    [Battery-Controller.kicad_pcb, Battery-Controller.sch]
2021-11-25 Mise à jour empreintes
    [Battery-Controller.kicad_pcb, Battery-Controller.sch]
2021-11-25 Mise en place composants
    [Battery-Controller.kicad_pcb, Battery-Controller.sch]
2021-12-01 Ajout logs SD Card
    [Battery-Controller.kicad_pcb, Battery-Controller.sch, batterie-controleur-diagrame-cablage-v2.fzz]
2021-12-02 Calibration entrées Cells
    [Battery-Controller.sch]
2021-12-02 Intégration des routines de surveillance de la température
    [Battery-Controller.kicad_pcb, Battery-Controller.sch]
2021-12-04 Print status, print params
2021-12-08 Optimisation du code
    [Battery-Controller.kicad_pcb, Battery-Controller.sch]
2021-12-14 Migration vers VS Code et PlatformIO
    [Battery-Controller.sch]
2021-12-14 Réécriture des codes d'erreur
2021-12-18 Fonctionne, correctement réglé, NO serial transfer
    [Battery-Controller.sch]
2021-12-19 RS484 included, not enough ram
    [Battery-Controller.sch]
2021-12-19 Utilisation de SdFat library
2021-12-20 Retrait de la verification des différences de cellules
2021-12-24 Bugfix highest cell voltage and lowest cell voltage
    [main.cpp]
2021-12-27 Mise à jour ADS1115 gain et calibration
2021-12-30 Print Params
